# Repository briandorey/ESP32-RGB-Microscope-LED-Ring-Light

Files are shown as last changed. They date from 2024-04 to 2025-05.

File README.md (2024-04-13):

# ESP32 RGB Microscope LED Ring Light
ESP32 based RGB LED controller and LED ring for a microscope

The **PCB files** are in Diptrace format.

The **firmware** folder contains the firmware for the ESP32 module

The **3D Models** folder contains design files for the plastic case.

More details about this project are on my blog at [https://www.briandorey.com/post/esp32-rgb-led-microscope-ringlight](https://www.briandorey.com/post/esp32-rgb-led-microscope-ringlight)

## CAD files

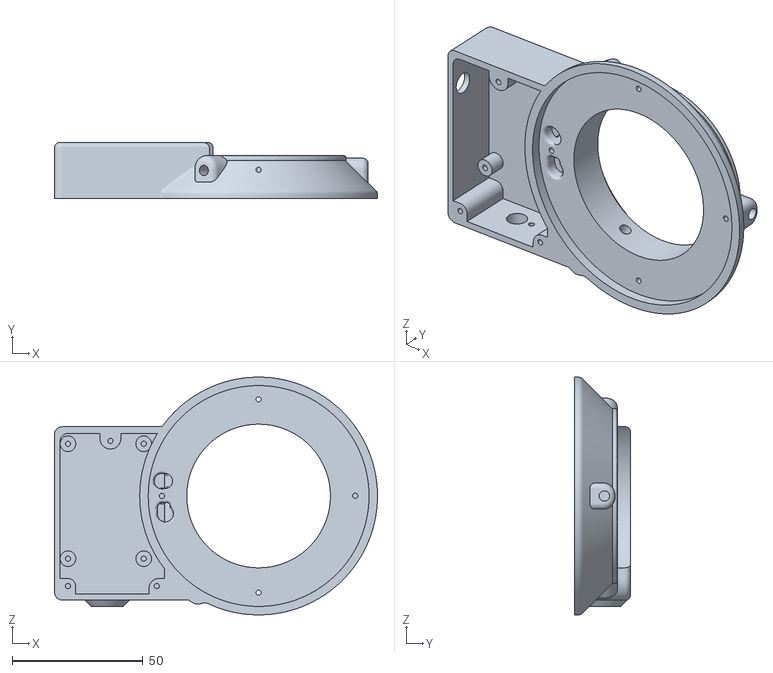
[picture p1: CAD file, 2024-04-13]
3D Models/Case.stl
123.7 x 21.5 x 91.1

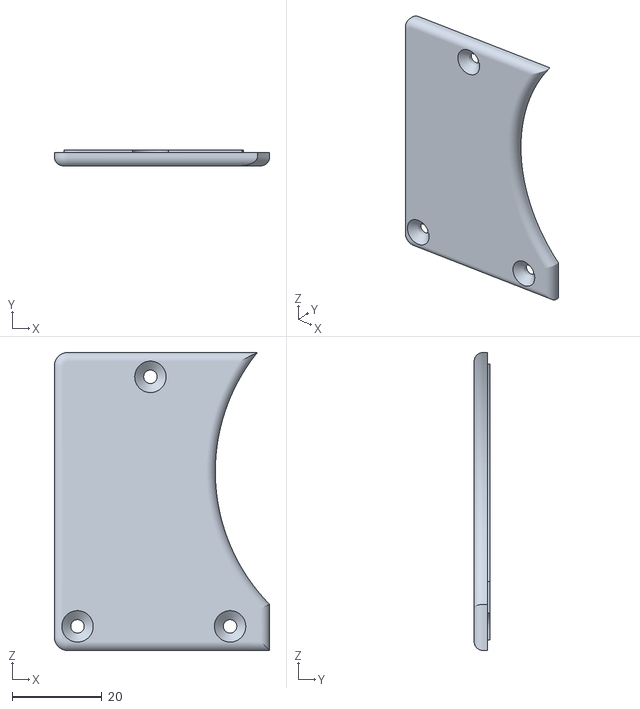
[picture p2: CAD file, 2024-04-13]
3D Models/Lid.stl
48.0 x 3.50 x 66.4

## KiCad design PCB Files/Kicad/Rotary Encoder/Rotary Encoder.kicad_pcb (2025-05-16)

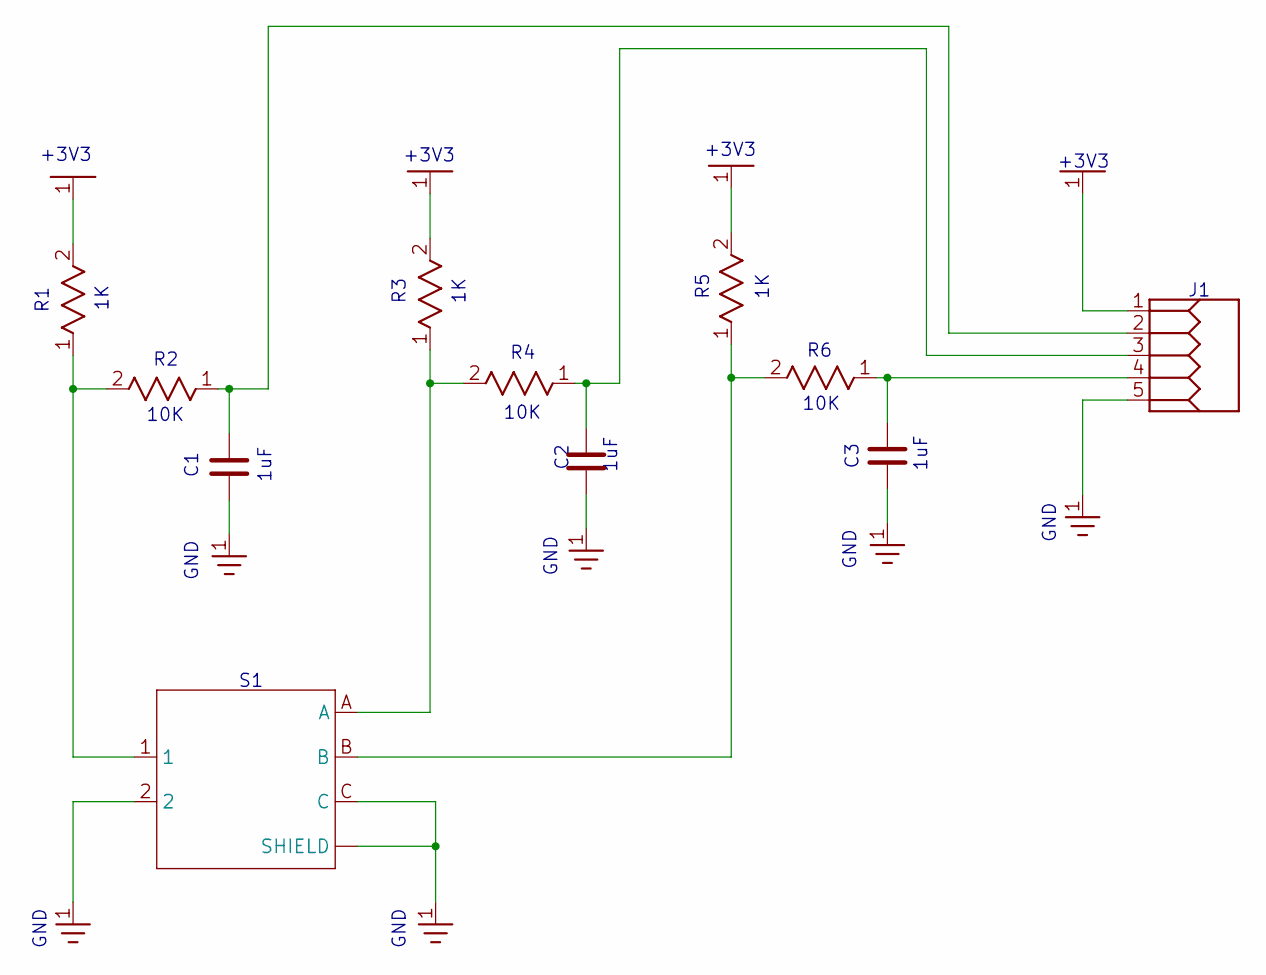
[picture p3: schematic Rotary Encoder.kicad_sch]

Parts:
C1, C2, C3: 1uF; CAP_0603
J1: DEV_J1; RHDRV5W80P254_5X1_1320X250H875_AP1
R1, R3, R5: 1K; RES_0603
R2, R4, R6: 10K; RES_0603
S1: 482020514001; SW_482020514001

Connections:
3V3: J1.1, R1.2, R3.2, R5.2
A: C2.1, J1.3, R4.1
B: C3.1, J1.4, R6.1
GND: C1.2, C2.2, C3.2, J1.5, S1.2, S1.C, S1.S1 (SHIELD), S1.S2 (SHIELD)
Net_1: R1.1, R2.2, S1.1
Net_5: R3.1, R4.2, S1.A
Net_7: R5.1, R6.2, S1.B
SW: C1.1, J1.2, R2.1

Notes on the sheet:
GND
+3V3
1uF
10K

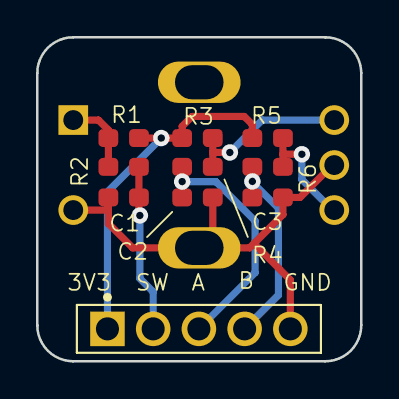
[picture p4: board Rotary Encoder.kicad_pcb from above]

Board: 2 copper layers, 18.0 x 18.0 mm, 11 parts (1 on the bottom side), 8 nets.

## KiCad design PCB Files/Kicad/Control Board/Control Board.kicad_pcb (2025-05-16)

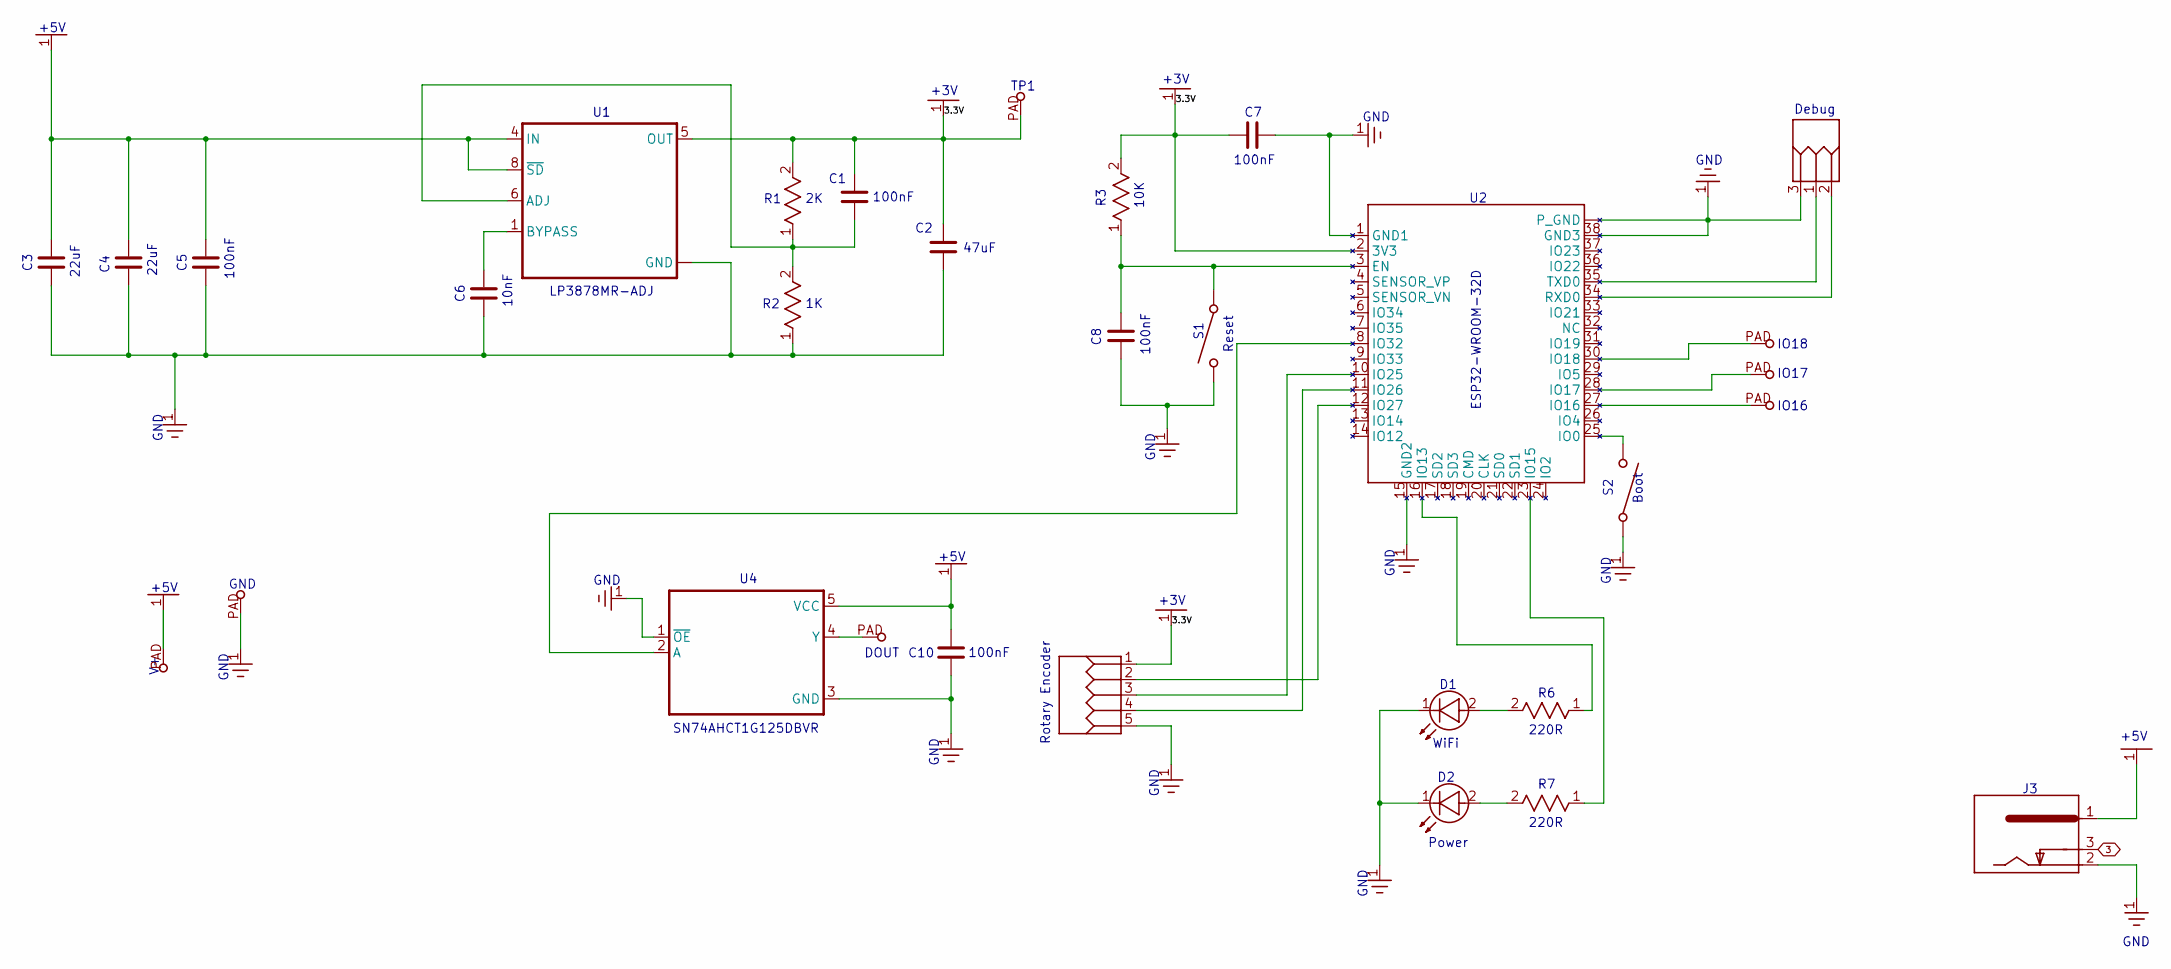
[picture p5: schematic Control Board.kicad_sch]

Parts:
C1, C5, C7, C8, C10: 100nF; CAP_0603_M
C2: 47uF; CAP_1210_M
C3, C4: 22uF; CAP_1210_M
C6: 10nF; CAP_0603_M
D1: WiFi; DIO_0805
D2: Power; DIO_0805
DOUT0: SMD/RREC2.0X4.0; LEAD_1.00MM
GND0: SMD/RREC2.0X4.0; LEAD_1.00MM
IO16, IO17, IO18: SMD/RREC2.0X4.0; LEAD_1.00MM
J1: DEBUG; TEST_PADS_3_PIN
J2: ROTARY_ENCODER; RHDRV5W80P254_5X1_1320X250H875_AP1
J3: 694108301002; CUI_PJ-035DH
R1: 2K; RES_0603
R2: 1K; RES_0603
R3: 10K; RES_0603
R6, R7: 220R; RES_0603_19
S1: RESET; EVQPT9A15
S2: BOOT; EVQPT9A15
TP1: 3V3; SMD_R1.3X1.3
U1: LP3878MR-ADJ; SOIC-8EP_150MIL
U2: ESP32-WROOM-32D
U4: SN74AHCT1G125DBVR; SOT95P280X145-5N
V+0: SMD/RREC2.0X4.0; LEAD_1.00MM

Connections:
3.3V: C1.1, C2.1, C7.1, J2.1, R1.2, R3.2, TP1.PAD, U1.5 (OUT), U2.2 (3V3)
5V: C3.1, C4.1, C5.1, C10.1, J3.1, U1.4 (IN), U1.8 (~SD), U4.5 (VCC), V+0.PAD
GND: C2.2, C3.2, C4.2, C5.2, C6.2, C7.2, C8.2, C10.2, D1.1 (K), D2.1 (K), GND0.PAD, J1.3 (1), J2.5, J3.2, R2.1, S1.2 (C2), S1.3 (C2), S2.1 (C1), S2.4 (C1), U1.3 (GND), U1.9 (GND), U2.1 (GND1), U2.15 (GND2), U2.38 (GND3), U2.39 (P_GND), U2.40, U2.41, U2.42 (P_GND), U2.43 (P_GND), U2.44, U2.45, U2.46, U2.47, U4.1 (~OE), U4.3 (GND); also elsewhere on the board
Net_0: U2.8 (IO32), U4.2 (A)
Net_1: R7.1 (A), U2.23 (IO15)
Net_2: J2.4, U2.11 (IO26)
Net_3: IO16.PAD, U2.27 (IO16)
Net_6: S2.2 (C2), S2.3 (C2), U2.25 (IO0)
Net_7: J2.3, U2.10 (IO25)
Net_8: C8.1, R3.1, S1.1 (C1), S1.4 (C1), U2.3 (EN)
Net_10: DOUT0.PAD, U4.4 (Y)
Net_11: R6.1 (A), U2.16 (IO13)
Net_12: J2.2, U2.12 (IO27)
Net_13: D1.2 (A), R6.2 (B)
Net_14: D2.2 (A), R7.2 (B)
Net_18: C6.1, U1.1 (BYPASS)
Net_19: C1.2, R1.1, R2.2, U1.6 (ADJ)
Net_20: IO17.PAD, U2.28 (IO17)
Net_21: IO18.PAD, U2.30 (IO18)
RX: J1.2 (3), U2.34 (RXD0)
TX: J1.1 (2), U2.35 (TXD0)

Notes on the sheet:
+5V
GND
+3V
100nF
Boot
47uF
Debug
IO17
10nF
22uF
220R
Reset
Power
10K
IO16
SN74AHCT1G125DBVR
WiFi
DOUT
LP3878MR-ADJ
Rotary Encoder
C10
IO18
TP1
ESP32-WROOM-32D

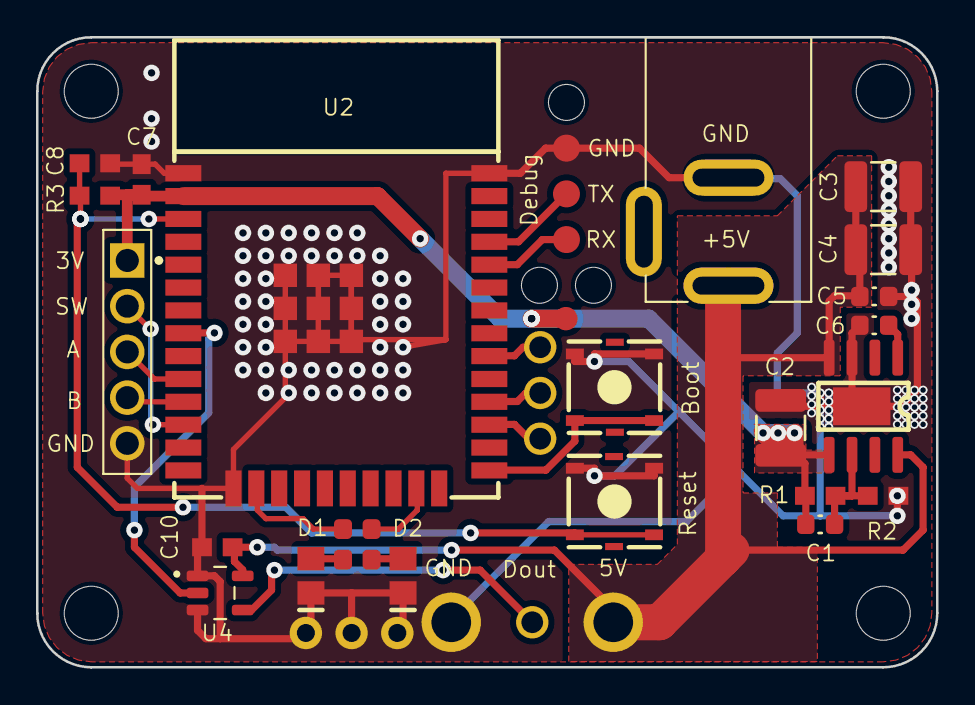
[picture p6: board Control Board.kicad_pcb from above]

Board: 2 copper layers, 50.0 x 35.0 mm, 38 parts (0 on the bottom side), 21 nets.

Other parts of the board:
Pad1, Pad2, Pad3: PAD; Pad
UNK_HOLE_0: dummyfp0
UNK_HOLE_1: dummyfp1
UNK_HOLE_2: dummyfp2
UNK_HOLE_3: dummyfp3

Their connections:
GND: Pad1.1, Pad2.1, Pad3.1; also elsewhere on the board

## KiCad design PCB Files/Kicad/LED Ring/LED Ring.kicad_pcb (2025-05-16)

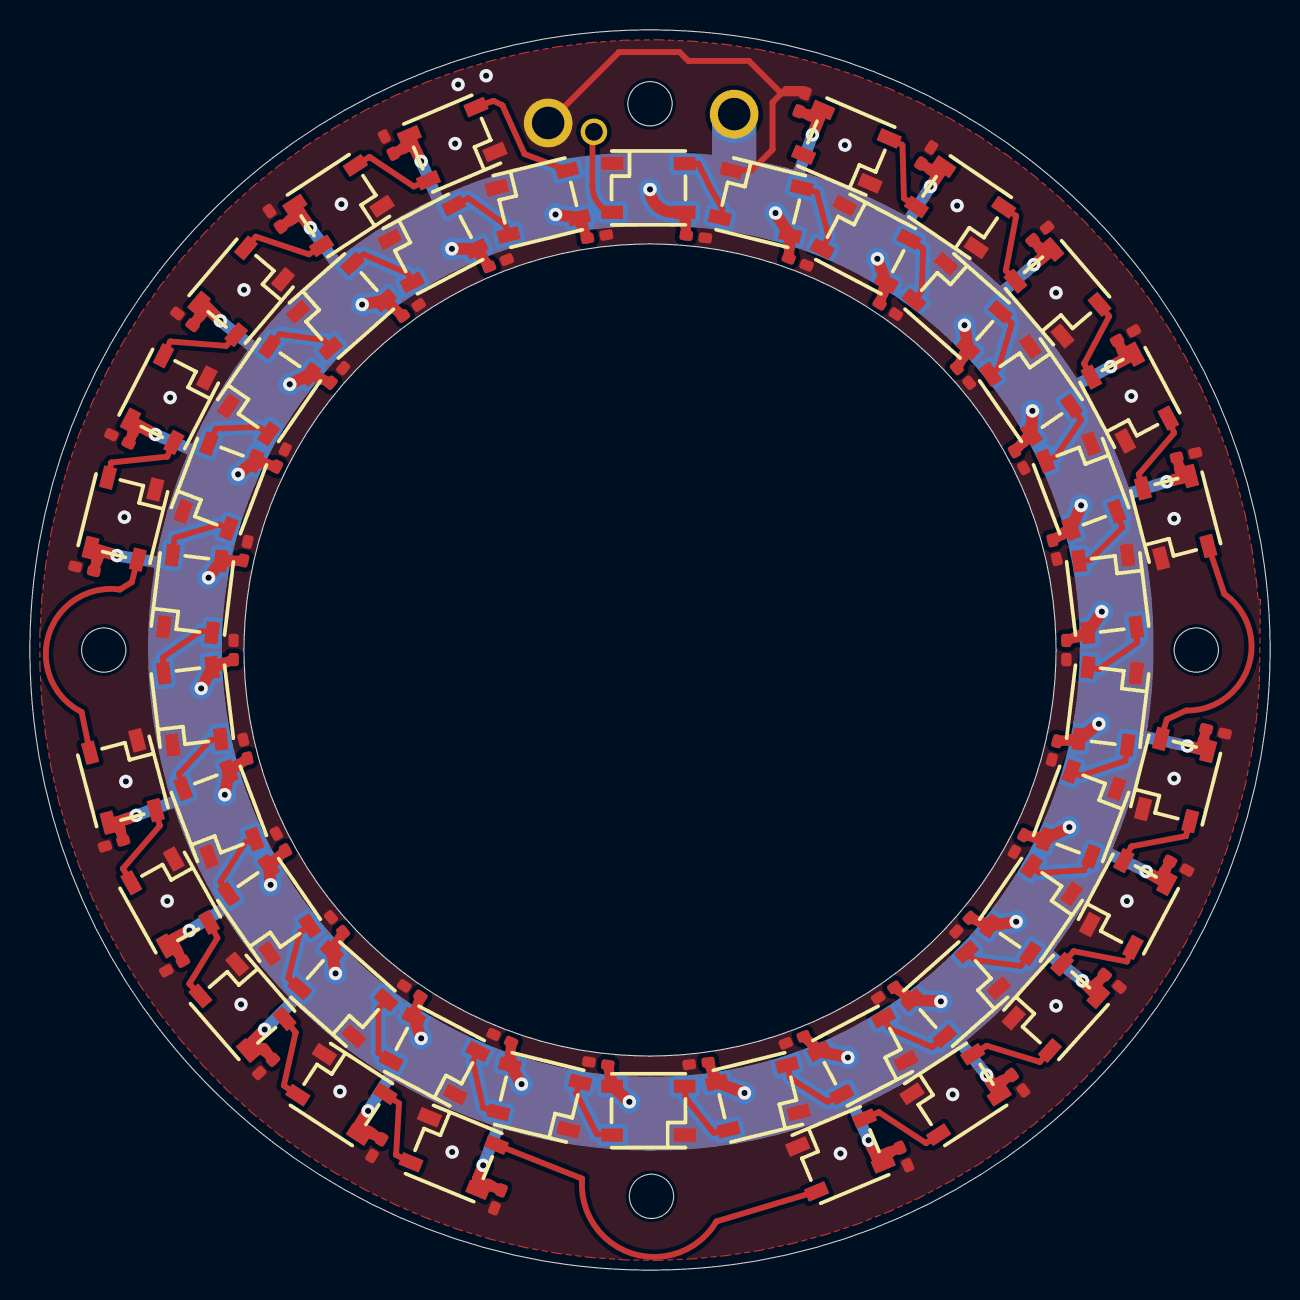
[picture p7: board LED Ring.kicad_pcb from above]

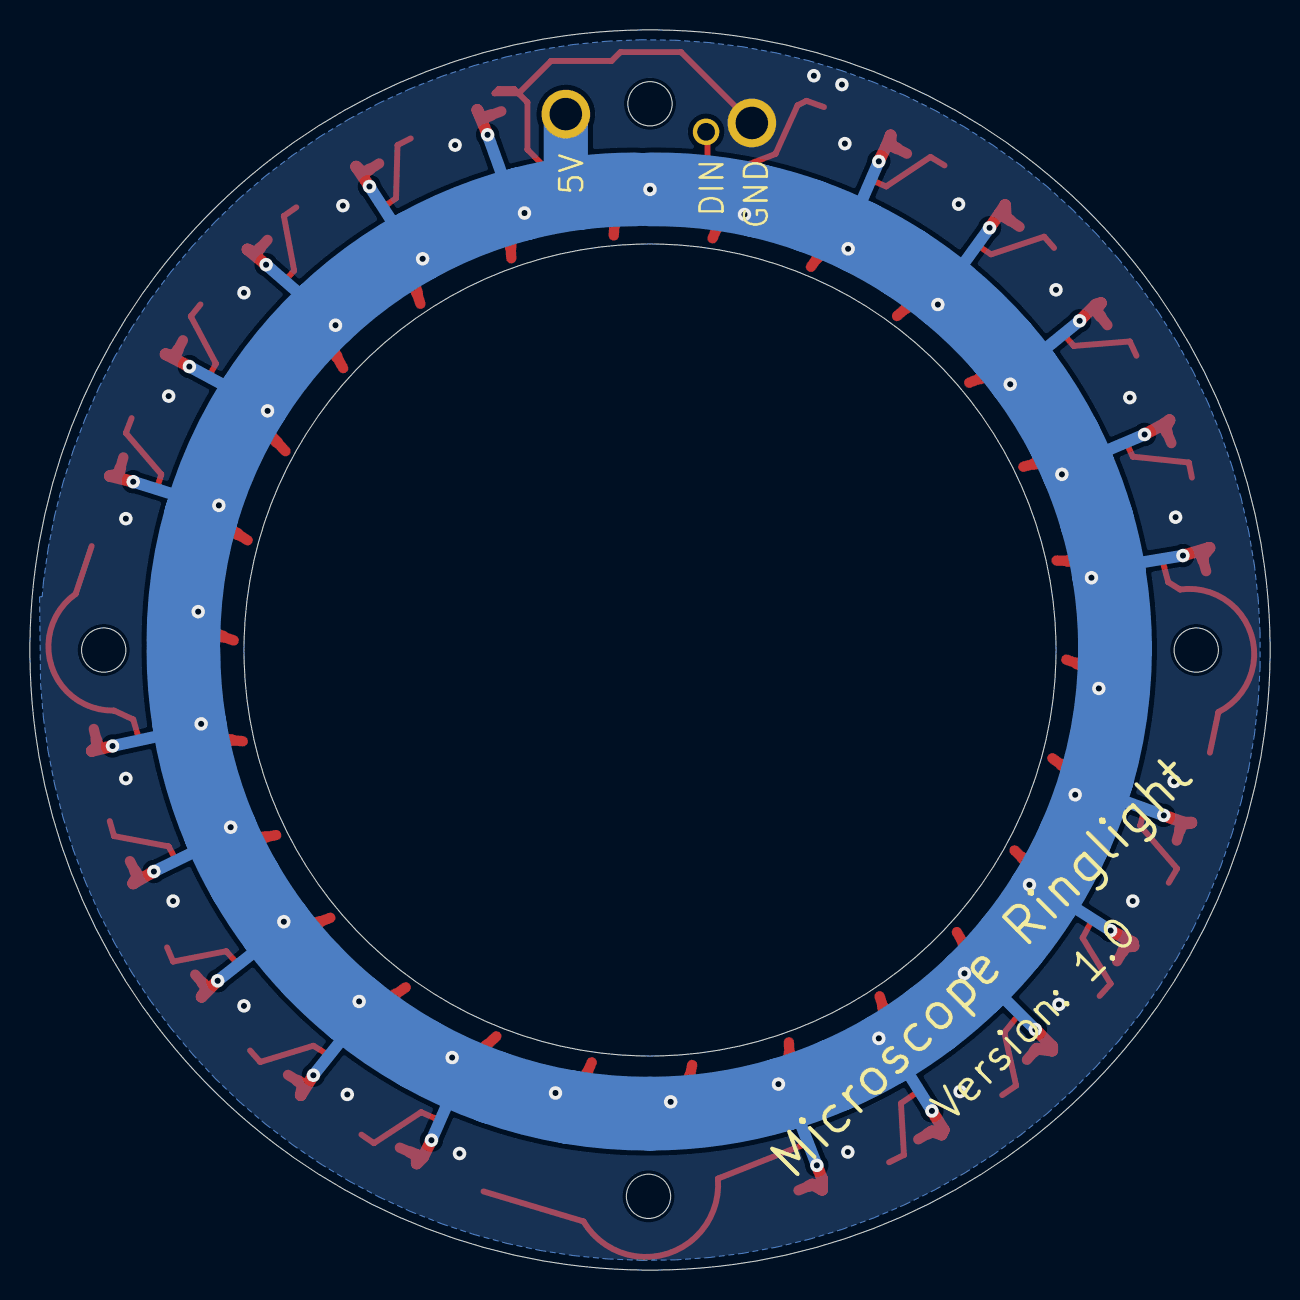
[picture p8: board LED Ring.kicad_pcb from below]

Board: 2 copper layers, 84.0 x 84.0 mm, 99 parts (3 on the bottom side), 48 nets.

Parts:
C1, C2, C3, C4, C5, C6, C7, C8, C9, C10, C11, C12, C13, C14, C15, C16, C17, C18, C19, C20, C21, C22, C23, C24, C25, C26, C27, C28, C29, C30, C31, C32, C33, C34, C35, C36, C37, C38, C39, C40, C41, C42, C43, C44, C45, C46: CAP_0603; CAP_0402
DIN0: SMD/RREC2.0X4.0; Lead_1.00mm
GND0: SMD/RREC2.0X4.0; Lead_2.00mm
LED1, LED2, LED3, LED4, LED5, LED6, LED7, LED8, LED9, LED10, LED11, LED12, LED13, LED14, LED15, LED16, LED17, LED18, LED19, LED20, LED21, LED22, LED23, LED24, LED25, LED26, LED27, LED28, LED29, LED30, LED31, LED32, LED33, LED34, LED35, LED36, LED37, LED38, LED39, LED40, LED41, LED42, LED43, LED44, LED45, LED46: WS2812B
UNK_HOLE_0: dummyfp0
UNK_HOLE_1: dummyfp1
UNK_HOLE_2: dummyfp2
UNK_HOLE_3: dummyfp3
V+0: SMD/RREC2.0X4.0; Lead_2.00mm

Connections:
Net_0: C1.1, C2.1, C3.1, C4.1, C5.1, C6.1, C7.1, C8.1, C9.1, C10.1, C11.1, C12.1, C13.1, C14.1, C15.1, C16.1, C17.1, C18.1, C19.1, C20.1, C21.1, C22.1, C23.1, C24.1, C25.1, C26.1, C27.1, C28.1, C29.1, C30.1, C31.1, C32.1, C33.1, C34.1, C35.1, C36.1, C37.1, C38.1, C39.1, C40.1, C41.1, C42.1, C43.1, C44.1, C45.1, C46.1, LED1.1, LED2.1, LED3.1, LED4.1, LED5.1, LED6.1, LED7.1, LED8.1, LED9.1, LED10.1, LED11.1, LED12.1, LED13.1, LED14.1, LED15.1, LED16.1, LED17.1, LED18.1, LED19.1, LED20.1, LED21.1, LED22.1, LED23.1, LED24.1, LED25.1, LED26.1, LED27.1, LED28.1, LED29.1, LED30.1, LED31.1, LED32.1, LED33.1, LED34.1, LED35.1, LED36.1, LED37.1, LED38.1, LED39.1, LED40.1, LED41.1, LED42.1, LED43.1, LED44.1, LED45.1, LED46.1, V+0.PAD
Net_1: C1.2, C2.2, C3.2, C4.2, C5.2, C6.2, C7.2, C8.2, C9.2, C10.2, C11.2, C12.2, C13.2, C14.2, C15.2, C16.2, C17.2, C18.2, C19.2, C20.2, C21.2, C22.2, C23.2, C24.2, C25.2, C26.2, C27.2, C28.2, C29.2, C30.2, C31.2, C32.2, C33.2, C34.2, C35.2, C36.2, C37.2, C38.2, C39.2, C40.2, C41.2, C42.2, C43.2, C44.2, C45.2, C46.2, GND0.PAD, LED1.3, LED2.3, LED3.3, LED4.3, LED5.3, LED6.3, LED7.3, LED8.3, LED9.3, LED10.3, LED11.3, LED12.3, LED13.3, LED14.3, LED15.3, LED16.3, LED17.3, LED18.3, LED19.3, LED20.3, LED21.3, LED22.3, LED23.3, LED24.3, LED25.3, LED26.3, LED27.3, LED28.3, LED29.3, LED30.3, LED31.3, LED32.3, LED33.3, LED34.3, LED35.3, LED36.3, LED37.3, LED38.3, LED39.3, LED40.3, LED41.3, LED42.3, LED43.3, LED44.3, LED45.3, LED46.3
Net_2: LED1.2, LED2.4
Net_3: LED2.2, LED3.4
Net_4: LED3.2, LED4.4
Net_5: LED4.2, LED5.4
Net_6: LED5.2, LED6.4
Net_7: LED6.2, LED7.4
Net_8: LED7.2, LED8.4
Net_9: LED8.2, LED9.4
Net_10: LED9.2, LED10.4
Net_11: LED19.2, LED20.4
Net_12: LED18.2, LED19.4
Net_13: LED17.2, LED18.4
Net_14: LED16.2, LED17.4
Net_15: LED15.2, LED16.4
Net_16: LED14.2, LED15.4
Net_17: LED13.2, LED14.4
Net_18: LED12.2, LED13.4
Net_19: LED11.2, LED12.4
Net_20: LED21.2, LED22.4
Net_21: LED22.2, LED23.4
Net_22: LED23.2, LED24.4
Net_23: LED24.2, LED25.4
Net_24: LED25.2, LED26.4
Net_25: LED26.2, LED27.4
Net_26: LED27.2, LED28.4
Net_27: LED28.2, LED29.4
Net_28: LED29.2, LED30.4
Net_29: LED39.2, LED40.4
Net_30: LED38.2, LED39.4
Net_31: LED37.2, LED38.4
Net_32: LED36.2, LED37.4
Net_33: LED35.2, LED36.4
Net_34: LED34.2, LED35.4
Net_35: LED33.2, LED34.4
Net_36: LED32.2, LED33.4
Net_37: LED31.2, LED32.4
Net_38: LED10.2, LED11.4
Net_39: LED20.2, LED21.4
Net_40: DIN0.PAD, LED1.4
Net_44: LED45.2, LED46.4
Net_45: LED44.2, LED45.4
Net_46: LED43.2, LED44.4
Net_47: LED42.2, LED43.4
Net_48: LED41.2, LED42.4
Net_49: LED30.2, LED31.4
Net_50: LED40.2, LED41.4

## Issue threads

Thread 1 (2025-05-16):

PCB files in EAGLE format (or other portable format)

dangermousehouse, 2025-05-16:
Hi, Thank you for sharing this amazing project - it really is the coolest thing, I'd love to follow along your blog/videos and try for myself.

Diptrace is a rare and exotic beast for us Mac users. Please consider the possibility of exporting the files in EAGLE format for easy portability into other CAD/EDA tools (like Kicad or EasyEDA)

Thankyou

briandorey, 2025-05-16:
We have converted the files from Diptrace into Kicad using the Eagle export but this dosnt work 100% of the time so hopefully everthing is the same.

Closed 2025-05-16.

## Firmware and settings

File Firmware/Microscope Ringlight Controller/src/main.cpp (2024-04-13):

#include <Arduino.h>
#include <WiFi.h>
#include "LEDController.h"
#include "WebController.h"
#include <ESPmDNS.h>
#include "Debug.h"
#include "SPIFFS.h"

// Status LEDs
const uint8_t LED_D1 = 13; // D1 Status LED
const uint8_t LED_D2 = 15; // D2 Status LED

// Information about the rotary encoder
const uint8_t ENCODER_A_PIN = 25; // ESP32 pin GPIO25 connected to encoder pin A
const uint8_t ENCODER_B_PIN = 26; // ESP32 pin GPIO26 connected to encoder pin B
const uint8_t ENCODER_SWITCH_PIN = 27; // ESP32 pin GPIO27 connected to encoder switch
static volatile uint64_t encoderLastSwitchTime = 0;
static volatile uint64_t encoderSwitchStartTime = 0;

enum EncoderStates{Stationary, CounterClockwise, Clockwise};
static volatile EncoderStates encoderRotationFlag = Stationary; // signals a change in the encoder rotation
static volatile bool encoderSwitchChangeStateFlag = false; // signals a switch press
static volatile bool encoderSwitchPressedFlag = false; // signals a switch press
static volatile bool encoderSwitchLongPressedFlag = false; // signals a switch long press

// Information about the web server
const char* HOST_NAME = "microscope";

LEDController ledController;
WebController webController(ledController);

const char* ssid = "wifissid";
const char* password = "wifipassword";

void IRAM_ATTR ISR_encoder_rotation() {
    uint8_t pinAState = digitalRead(ENCODER_A_PIN);
    uint8_t pinBState = digitalRead(ENCODER_B_PIN);

    if (pinAState == HIGH && pinBState == HIGH) {
        // the encoder is rotating in counter-clockwise direction
        if (encoderRotationFlag == Stationary) {
            encoderRotationFlag = CounterClockwise;
        }
    } else if (pinAState == LOW && pinBState == HIGH) {
        // the encoder is rotating in clockwise direction
        if (encoderRotationFlag == Stationary) {
            encoderRotationFlag = Clockwise;
        }
    }
}

void IRAM_ATTR ISR_encoder_switch() {
    if ((millis() - encoderLastSwitchTime) < 50) { // debounce time is 50ms
        return;
    }
    encoderSwitchChangeStateFlag = true;
    encoderLastSwitchTime = millis();
}

void setup() {
    #ifdef DEBUG
        Serial.begin(115200);
    #endif

    // Rotary Encoder Setup

    // configure encoder pins as inputs
    pinMode(ENCODER_A_PIN, INPUT);
    pinMode(ENCODER_B_PIN, INPUT);
    pinMode(ENCODER_SWITCH_PIN, INPUT);

    // configure LED pins as outputs
    pinMode(LED_D1, OUTPUT);
    pinMode(LED_D2, OUTPUT);

    digitalWrite(LED_D1, HIGH); // Set D1 Led high to show the device is powered

    bool failed = false; // flag for checking if setup completes successfully

    // call ISR_encoder() when CLK pin changes from LOW to HIGH
    attachInterrupt(digitalPinToInterrupt(ENCODER_B_PIN), ISR_encoder_rotation, RISING);

    // call ISR_encoder() when CLK pin changes from HIGH to LOW
    attachInterrupt(digitalPinToInterrupt(ENCODER_SWITCH_PIN), ISR_encoder_switch, CHANGE);

    ledController.begin(); // Initialize the LED controller object

    // Initialize SPIFFS
    if(!SPIFFS.begin(true)){
        TRACE("An Error has occurred while mounting SPIFFS")
        failed = true;
        ledController.showError(LEDController::ErrorFlashMem);
    }

    // Initialize the Wi-Fi module
    WiFiClass::mode(WIFI_STA);

    WiFiClass::setHostname(HOST_NAME);
    WiFi.begin(ssid, password);
    if (WiFi.waitForConnectResult() != WL_CONNECTED) {
        TRACE("WiFi Failed!\n")
        failed = true;
        ledController.showError(LEDController::ErrorNoWifi);
    }
    else{ // Wi-Fi connected
        TRACE("IP Address: ")
        TRACELN(WiFi.localIP())
    }

    if(!MDNS.begin(HOST_NAME)) {
        TRACELN("Error starting mDNS")
        failed = true;
        ledController.showError(LEDController::ErrorGeneralException);
    }
    else{
        // Advertise the services
        MDNS.addService("http", "tcp", 80);
    }

    if (failed) {
        digitalWrite(LED_D2, HIGH); // Set D2 LED high to show an error has occurred.
    }
    else{
        webController.begin();
    }
}

void loop() {
    if (encoderSwitchChangeStateFlag) {
        delay(10); // wait 10ms for button to stabilize
        if (digitalRead(ENCODER_SWITCH_PIN) == 0){ // button is pressed
            if (!encoderSwitchPressedFlag){
                encoderSwitchStartTime = millis();
                encoderSwitchPressedFlag = true;
                encoderSwitchLongPressedFlag = false;
            }
        }
        else{ // button is released
            encoderSwitchStartTime = 0;
            encoderSwitchPressedFlag = false;
            if (!encoderSwitchLongPressedFlag && ledController.currentMode != LEDController::ModeOff) {
                TRACELN("short press")
                ledController.changeMode();
            }
            encoderSwitchLongPressedFlag = false;
        }

        encoderSwitchChangeStateFlag = false;
        encoderLastSwitchTime = millis();
    }

    if (encoderSwitchPressedFlag){
        if (millis() - encoderSwitchStartTime > 2000){ // button pressed for more than 2 seconds
            TRACELN("Long press")
            if (ledController.currentMode == LEDController::ModeOff) {
                LEDController::On();
            } else {
                LEDController::Off(); // turn light off
            }
            encoderSwitchStartTime = 0;
            encoderSwitchPressedFlag = false;
            encoderSwitchLongPressedFlag = true;
        }
    }

    if (encoderRotationFlag == Clockwise){ // Encoder has rotated clockwise
        delay(10); // wait 10ms for button to stabilize
        ledController.Up();
        encoderRotationFlag = Stationary;
    }
    else if (encoderRotationFlag == CounterClockwise){ // Encoder has rotated counter-clockwise
        delay(10); // wait 10ms for button to stabilize
        ledController.Down();
        encoderRotationFlag = Stationary;
    }

    ledController.Process(); // process the next event in the LED operations queue
}

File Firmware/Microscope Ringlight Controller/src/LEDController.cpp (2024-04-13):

#include "LEDController.h"
#include <queue>

static Preferences preferences;

// Information about the default program values
const uint8_t DEFAULT_BRIGHTNESS = 150;
const uint16_t DEFAULT_TEMPERATURE = 4500;

// Information about the colours the LEDs will flash when setting a mode
const CRGB MODE_BRIGHTNESS_COLOUR = CRGB(0, 0, 255); // blue
const CRGB MODE_TEMPERATURE_COLOUR = CRGB(255, 0, 255); // purple
const CRGB MODE_DIRECTION_COLOUR = CRGB(0, 255, 0); // green
const uint16_t MODE_FLASH_DURATION = 500; // 0.5s

// Event Operation
enum EventOperations{BrightnessOperation = 1, TemperatureOperation = 2, DirectionOperation = 3, PowerOperation = 4};

static CRGB LEDs[LED_COUNT];

// Define a struct to represent an event
struct LEDEvent {
    EventOperations name;
    uint16_t parameter;

    LEDEvent(EventOperations name, int parameter)
            : name(name), parameter(parameter) {}
};

std::queue<LEDEvent> LedEvents;

void LEDController::Process(){
    // Process the event queue
    while (!LedEvents.empty()) {
        LEDEvent ev = LedEvents.front(); // Get the operation at the front of the queue
        LedEvents.pop(); // Remove the operation from the queue

        switch (ev.name){
            case BrightnessOperation:
                BrightnessEvent(ev.parameter);
                break;
            case TemperatureOperation:
                TemperatureEvent(ev.parameter);
                break;

            case DirectionOperation:
                DirectionEvent(ev.parameter);
                break;

            case PowerOperation:
                PowerEvent(ev.parameter);
                break;
            default:
                break;
        }
    }
}

void LEDController::begin(){
    // Set variable values
    // LED Variables

    currentDirection = 0;

    // Initialize the LED ring
    CFastLED::addLeds<CHIPSET, LED_PIN, GRB>(LEDs, LED_COUNT);

    // Retrieve variables
    preferences.begin("storage", false);
    currentBrightness = preferences.getUChar("brightness", DEFAULT_BRIGHTNESS);
    uint16_t retrievedTemperature = preferences.getUShort("temperature", DEFAULT_TEMPERATURE);
    preferences.end();

    TRACELN("Loaded State")
    TRACE("Brightness: ")
    TRACE(currentBrightness)
    TRACE("\nTemperature: ")
    TRACE(retrievedTemperature)
    TRACE("\n\n")

    if (retrievedTemperature >= 1000 && retrievedTemperature <= 12000){
        currentTemperature = retrievedTemperature;
    }
    else{
        currentTemperature = DEFAULT_TEMPERATURE;
    }

    currentMode = ModeBrightness;
    setTemperature(currentTemperature);
    setBrightness(currentBrightness);
}

void LEDController::TemperatureEvent(uint16_t kelvin) {

    TRACELN("Temperature: ")
    TRACE(kelvin)
    TRACE("\n")
    // Sets kelvin temperature value between 700 and 12000
    if (kelvin < 700 || kelvin > 12000) {
        return;
    }

    uint16_t temp;
    temp = uint16_t(kelvin / 100.0);
    int red, green, blue;
    // Calculate Red
    if (temp <= 66) {
        red = 255;
    } else {
        red = temp - 60;
        red = int(329.698727446 * (pow(red, -0.1332047592)));
        red = std::min(std::max(red, 0), 255);
    }

    // Calculate Green
    if (temp <= 66) {
        green = temp;
        green =  int(99.4708025861 * log(green) - 161.1195681661);
        green = std::min(std::max(int(green), 0), 255);
    } else {
        green = temp - 60;
        green =  int(288.1221695283 * (pow(green, -0.0755148492)));
        green = std::min(std::max(green, 0), 255);
    }

    // Calculate Blue
    if (temp >= 66) {
        blue = 255;
    } else if (temp <= 19) {
        blue = 0;
    } else {
        blue = temp - 10;
        blue = int(138.5177312231 * log(blue) - 305.0447927307);
        blue = std::min(std::max(blue, 0), 255);
    }

    for(auto & led : LEDs) {
        // let's set an led value
        led = CRGB(red, green, blue);
    }

    currentTemperature = kelvin;
    FastLED.show();
    saveState();
}
void LEDController::BrightnessEvent(uint16_t brightness){
    TRACE("Brightness: ")
    TRACE(brightness)
    TRACE("\n")
    if (brightness >= 0 && brightness <= 255) {
        FastLED.setBrightness(brightness);
        FastLED.show();
        currentBrightness = brightness;
        saveState();
    }
}

void LEDController::DirectionEvent(uint16_t direction) {
    // direction value 0 to 26
    TRACE("Direction: ")
    TRACE(direction)
    TRACE("\n")

    uint8_t position;

    if (direction == 0){ // turn on all LEDs
        for(auto & LED : LEDs) {
            LED = CRGB(255,255,255);
        }
    }
    else{
        // turn off all LEDs
        for(auto & LED : LEDs) {
            // let's set an led value
            LED = CRGB(0,0,0);
        }

        // turn on 5 inner LEDs
        for(uint8_t i = 0; i < 5; i++) {
            // let's set an led value
            position = i + direction;
            if (position >= 26) position = position - 26;
            LEDs[position] = CRGB(255,255,255);
        }
        // turn on 4 outer LEDs
        for(uint8_t i = 0; i <  4; i++) {
            position = 46 - i - direction;
            if (direction > 5) position += 1; // offsets for bolts
            if (direction > 8) position += 1;
            if (direction > 13) position += 1;
            if (direction > 17) position += 1;
            if (direction > 21) position += 1;
            if (position < 26) position = position + 20;
            LEDs[position] = CRGB(255,255,255);
        }
    }
    currentDirection = static_cast<uint8_t>(direction);
    FastLED.show();
}

void LEDController::PowerEvent(bool state){
    if (state){ // turn on
        TRACELN("Power State: On")
        if (currentBrightness < 10) currentBrightness = 10;
        FastLED.setBrightness(currentBrightness);
        FastLED.show();
        currentMode = ModeBrightness;
    }
    else{ // turn off
        TRACELN("Power State: Off")
        saveState();
        FastLED.setBrightness(0);
        FastLED.show();
        currentMode = ModeOff;
    }
}

void LEDController::setTemperature(uint16_t kelvin){
    LedEvents.emplace(TemperatureOperation, kelvin);
}

void LEDController::setBrightness(uint16_t brightness){
    LedEvents.emplace(BrightnessOperation, brightness);
}

void LEDController::setDirection(uint16_t direction){
    LedEvents.emplace(DirectionOperation, direction);
}

void LEDController::Off(){
    LedEvents.emplace(PowerOperation, false);
}

void LEDController::On(){
    LedEvents.emplace(PowerOperation, true);
}

void LEDController::flashLEDs(CRGB colour) const{
    // Flash the LED ring for a short duration with a different colour
    FastLED.showColor(colour);
    delay(MODE_FLASH_DURATION);
    setTemperature(currentTemperature);
    setBrightness(currentBrightness);
}

void LEDController::showError(ErrorState error){
    // Flash the LEDs red to show an error has occured
    for (int i = 0; i < error; i++){
        flashLEDs(CRGB(255, 0 ,0));
    }
}
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

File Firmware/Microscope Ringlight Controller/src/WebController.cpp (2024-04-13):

#include "WebController.h"

AsyncWebServer webserver(80);

void WebController::begin(){
    // Initialize the web server

    // Route for root / web page
    webserver.on("/", HTTP_GET, [](AsyncWebServerRequest *request){
        request->send(SPIFFS, "/www/index.html", "text/html");
    });

    // Route to load style.css file
    webserver.on("/styles.css", HTTP_GET, [](AsyncWebServerRequest *request){
        request->send(SPIFFS, "/www/styles.css", "text/css");
    });

    // Route to load scripts.js file
    webserver.on("/scripts.js", HTTP_GET, [](AsyncWebServerRequest *request){
        request->send(SPIFFS, "/www/scripts.js", "text/javascript");
    });

    // GET Endpoints
    webserver.on("/getstate", HTTP_GET, [this](AsyncWebServerRequest *request) {
        // Send the response
        request->send(200, "application/json", LightsData());
    });

    // Route for receiving a POST request on "/power"
    webserver.on("/power", HTTP_POST, [](AsyncWebServerRequest *request) {}, nullptr, [this](AsyncWebServerRequest *request, uint8_t *data, size_t len, size_t index, size_t total) {
        // Allocate the JSON document
        JsonDocument doc;

        // Deserialize the JSON document
        DeserializationError error = deserializeJson(doc, (const char*)data);

        // Test if parsing succeeds
        if (error) {
            TRACELN(F("deserializeJson() failed: "))
            TRACELN(error.f_str())
            request->send(400, "application/json", R"({"message":"failed"})");
            return;
        }

        if (doc["power"] == 1){
            if (ledController.currentMode == LEDController::ModeOff) {
                LEDController::On();
            }
        }
        else{
            if (ledController.currentMode != LEDController::ModeOff) {
                LEDController::Off();
            }
        }
        request->send(200, "application/json", R"({"message":"success"})");
    });

    // Route for receiving a POST request on "/brightness"
    webserver.on("/brightness", HTTP_POST, [](AsyncWebServerRequest *request) {}, nullptr, [this](AsyncWebServerRequest *request, uint8_t *data, size_t len, size_t index, size_t total) {
        // Allocate the JSON document
        JsonDocument doc;

        // Deserialize the JSON document
        DeserializationError error = deserializeJson(doc, (const char*)data);

        // Test if parsing succeeds
        if (error) {
            TRACELN(F("deserializeJson() failed: "))
            TRACELN(error.f_str())
            request->send(400, "application/json", R"({"message":"failed"})");
            return;
        }

        uint8_t brightness = doc["brightness"];

        if (ledController.currentBrightness != brightness){
            LEDController::setBrightness(brightness);
        }

        request->send(200, "application/json", R"({"message":"success"})");
    });

    // Route for receiving a POST request on "/temperature"
    webserver.on("/temperature", HTTP_POST, [](AsyncWebServerRequest *request) {}, nullptr, [this](AsyncWebServerRequest *request, uint8_t *data, size_t len, size_t index, size_t total) {
        // Allocate the JSON document
        JsonDocument doc;

        // Deserialize the JSON document
        DeserializationError error = deserializeJson(doc, (const char*)data);

        // Test if parsing succeeds
        if (error) {
            TRACELN(F("deserializeJson() failed: "))
            TRACELN(error.f_str())
            request->send(400, "application/json", R"({"message":"failed"})");
            return;
        }

        uint16_t temperature = doc["temperature"];

        if (ledController.currentTemperature != temperature){
            LEDController::setTemperature(temperature);
        }

        request->send(200, "application/json", R"({"message":"success"})");
    });

    // Route for receiving a POST request on "/direction"
    webserver.on("/direction", HTTP_POST, [](AsyncWebServerRequest *request) {}, nullptr, [this](AsyncWebServerRequest *request, uint8_t *data, size_t len, size_t index, size_t total) {
        // Allocate the JSON document
        JsonDocument doc;

        // Deserialize the JSON document
        DeserializationError error = deserializeJson(doc, (const char*)data);

        // Test if parsing succeeds
        if (error) {
            TRACELN(F("deserializeJson() failed: "))
            TRACELN(error.f_str())
            request->send(400, "application/json", R"({"message":"failed"})");
            return;
        }

        uint8_t direction = doc["direction"];

        if (ledController.currentDirection != direction){
            LEDController::setDirection(direction);
        }

        request->send(200, "application/json", R"({"message":"success"})");
    });

    webserver.onNotFound(notFound);
    webserver.begin();
}

void WebController::notFound(AsyncWebServerRequest *request) {
    request->send(404, "text/plain", "Not found");
}

String WebController::LightsData() const {
    /// Allocate the JSON document with a specific size
    JsonDocument doc;

    doc["numberOfLights"] = 26;
    // Create the lights array
    JsonArray lights = doc["lights"].to<JsonArray>();

    // Add an object to the array using the add<JsonObject>() method
    JsonObject light = lights.add<JsonObject>();
    if (ledController.currentMode == LEDController::ModeOff) {
        light["on"] = 0;  // Light is off
    } else {
        light["on"] = 1;  // Light is on
    }
    light["brightness"] = ledController.currentBrightness;  // Brightness level
    light["temperature"] = ledController.currentTemperature;  // Color temperature
    light["direction"] = ledController.currentDirection;  // Direction

    // Serialize JSON document to String
    String response;
    serializeJson(doc, response);

    return response;
}

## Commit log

2024-04-13 initial upload
    [Case.stl, Lid.stl]
2025-05-16 Added kicad versions
    [Control Board.kicad_pcb, Control Board.kicad_sch, LED Ring.kicad_pcb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]
